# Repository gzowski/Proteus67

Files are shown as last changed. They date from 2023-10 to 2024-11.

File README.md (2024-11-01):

# Proteus67 - Ortholinear mechanical keyboard

* 67 Key ortholinear design, inspiration taken from the split design of the Sofle/Lily58 and Planck
* 33 keys per hand
* 1 Rotary encoder in the middle (Green)
* Additional column positioned each side down the centre. (Orange)
* Single microcontroller design while retaining characteristics of a split layout
* 130mm finger spacing while hands are at home positions (F/J keys) in a QWERTY layout. (Blue)

* As there is no base plate by default, I've provided PCB files and laser cutting stencils which can be fabricated, if mounting on a plate you'll also require M2 standoff's and screws.
* There is also a 3D printed case STL which fits the keyboard with the PCB resting on printed supports within the case, mounting screws not required.
* Firmware now part of QMK official repo: https://github.com/qmk/qmk_firmware
   * If you need any assistance with building your firmware then please reach out.
* Fully supported with VIA when flashed with VIA keymap: https://usevia.app/

### [Parts](#Parts) || [Assembly Guide](#Assembly-Guide)

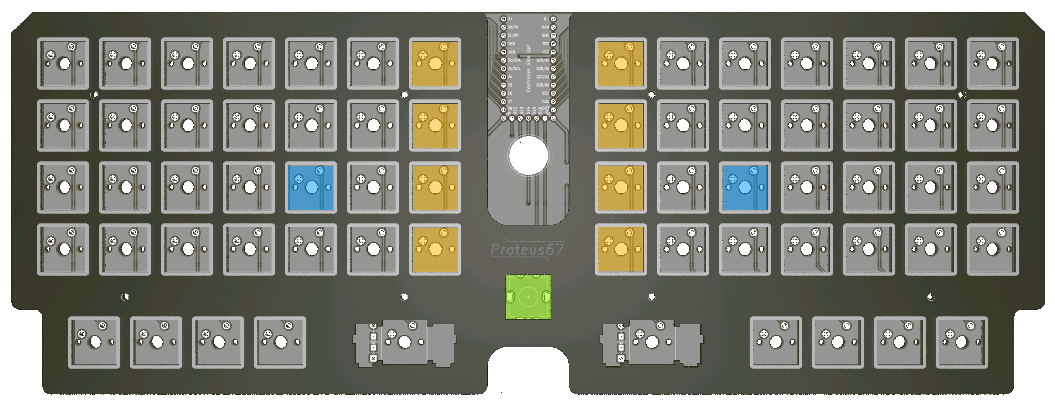
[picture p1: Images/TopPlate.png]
PCB

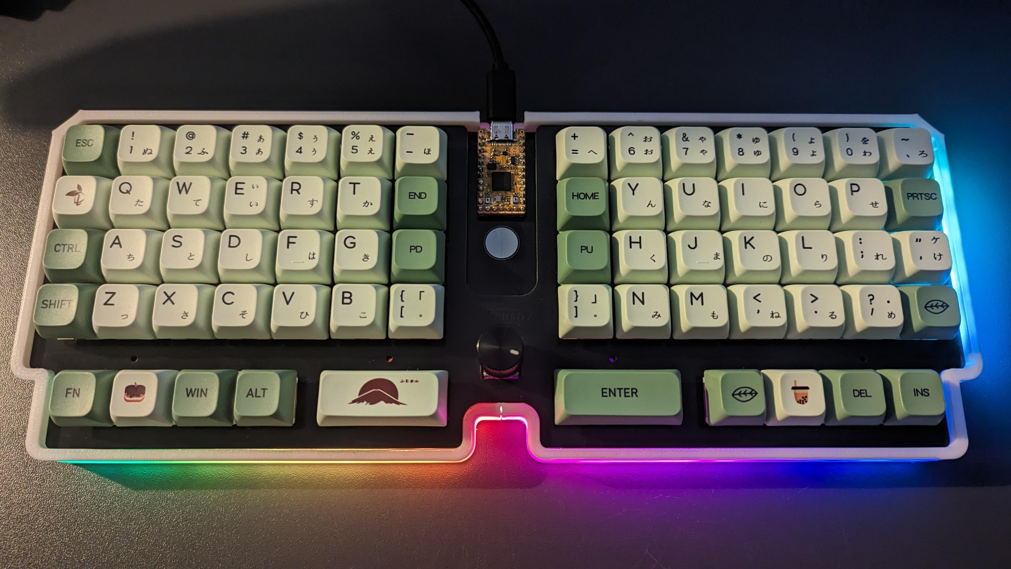
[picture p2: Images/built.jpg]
Personal build

## Parts

| Part | Quantity | Description | 
| :--- | :--- | :--- |
| Diodes| 67  | Through-hole 1N4148 or SMD 1N4148W |
| Microcontroller | 1 | 24 IO Pins required Elite-Pi/Frood or similar RP2040 |
| MX Switches | 66 | Cherry MX compatible switches |
| EC11 | 1 | Rotary Encoder for centre |
| MJTP1117 | 1 | Angled reset switch, (legs need cutting off) |
| Keycaps | 66 | 64x1u switches and 2x2u switches |
| Stabalizers | 2 | 2u plate mounted |

All components can be purchased through [mechboards.co.uk](https://mechboards.co.uk)

(Optional):
| Part | Quantity | Description |
| :--- | :--- | :--- |
| LED Strip | 1 | WS2812 Compatible (30cm) |
| 3D printed case | 1 | [3D printed case, STL/gcode](https://github.com/gzowski/Proteus67/tree/main/case) |
| PCB Base Plate | 1 | Bottom of case, covers underside |
| Base Plate Cutout | 1 | [STEP file of base plate outline which can be laser cut](https://github.com/gzowski/Proteus67/tree/main/case) |

## Assembly Guide

* I have provided additional images [here](https://github.com/gzowski/Proteus67/blob/main/Images/help_images.jpg) which show assembly.
* Place both stabalizers into the top plate
* Insert all switches into the top plate and put to the side
* Diode installation: Must be on the rear of the board due to lack of clearance from stabalisers.
  * SMD mounting: Use smaller diode points marked below, ensure diodes are facing the correct orientation
  * Through-Hole mounting: Use the wider spacing through-holes, ensuring diodes are facing the correct orientation.
    * Snip off excess on top side.
* Reset switch: snip off legs before positioning on board.
  *  Place switch on top side of PCB and solder from underside
* Microcontroller needs to be positioned with the top of the board facing upwards (Test controller beforehand and flash firmware using QMK)
* Place the rotary encoder on the top side and solder all points ensuring it stays flush to the board.
* Press down the top plate with switches and stabalisers down on the middle plate ensuring that all the switches sit flush against the middle plate.
* Turn board over and proceed to solder switches to the board
* Connect USB to keyboard and check all keys are functional, this is assuming you've already flashed the firmware to the MCU.

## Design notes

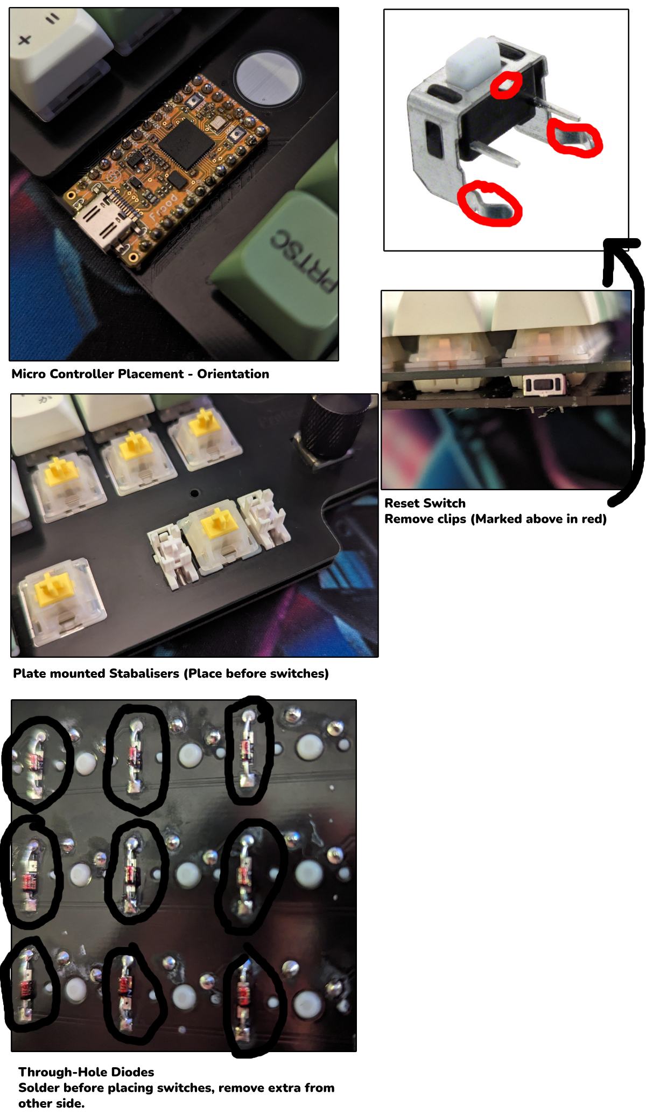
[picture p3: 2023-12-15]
Images/help_images.jpg

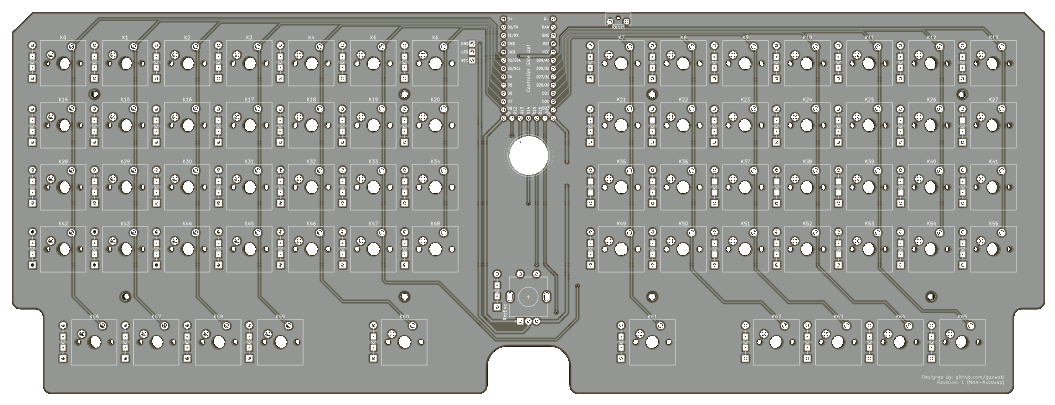
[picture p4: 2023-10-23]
Images/PCB.png

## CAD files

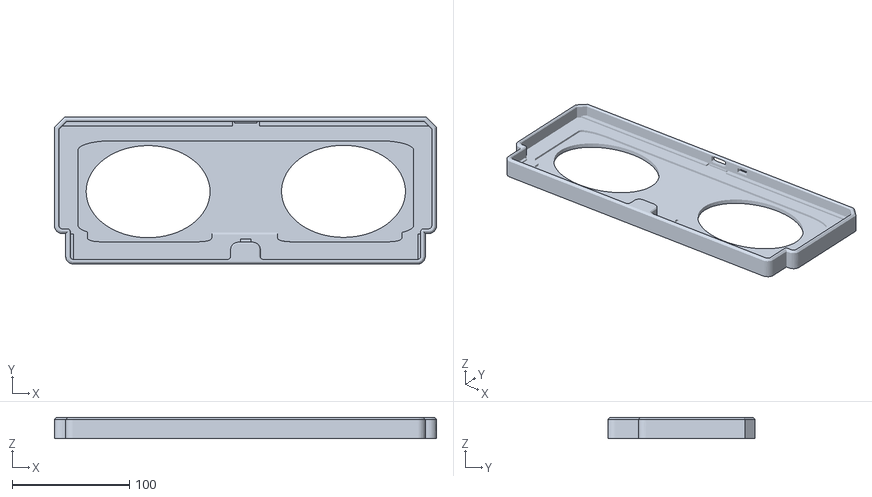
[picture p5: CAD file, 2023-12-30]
case/case_hollow_base_nocurve_front.stl
325.4 x 125.3 x 18.0

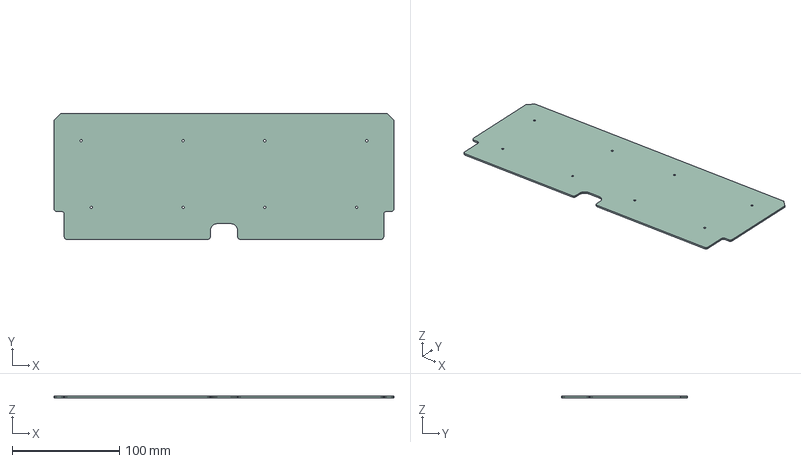
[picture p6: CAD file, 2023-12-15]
case/stencil for laser cutters/Plate.step
317.4 x 117.3 x 1.60 mm

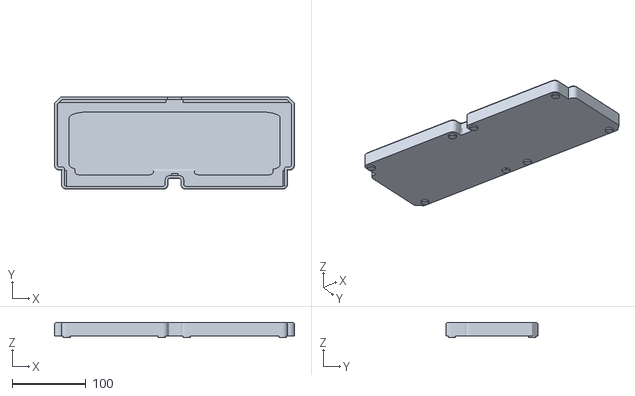
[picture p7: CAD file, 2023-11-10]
case/Case_original.stl
325.4 x 125.3 x 20.2

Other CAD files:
case/stencil for laser cutters/Plate.dxf

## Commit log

2023-10-15 Sun Oct 15 09:37:59 PM BST 2023
    [Proteus_Base.kicad_pcb, Proteus_PCB.kicad_pcb, Proteus_Top.kicad_pcb]
2023-10-16 Mon Oct 16 12:56:28 PM BST 2023
    [Lily58_Pro_TOP.kicad_pcb, Proteus_Top.kicad_pcb]
2023-10-16 Mon Oct 16 05:38:32 PM BST 2023
    [Proteus_Base.step, Proteus_Top.kicad_pcb, Proteus_Top.step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]
2023-10-17 Tue Oct 17 08:37:44 PM BST 2023
    [Proteus_PCB.kicad_pcb, base_Plate 1.stl]
2023-10-17 Tue Oct 17 08:39:14 PM BST 2023
    [top_Plate 1.stl]
2023-10-18 Wed Oct 18 11:14:47 AM BST 2023
    [Proteus_Top.step]
2023-10-23 Mon Oct 23 02:52:20 PM BST 2023
    [LeftPCB.stl, Proteus_Base.step, Proteus_PCB.kicad_pcb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]
2023-10-31 Tue Oct 31 12:33:12 PM GMT 2023
    [LeftPCB.stl, LeftPanel.stl, RightPCB.stl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]
2023-11-05 Sun Nov 5 11:47:03 PM GMT 2023
    [CaseFull.stl, LeftPanel.stl, RightPanel.stl]
2023-11-09 Thu Nov 9 10:01:54 PM GMT 2023
    [Proteus_Base-Edge_Cuts.dxf]
2023-11-10 Fri Nov 10 05:08:51 PM GMT 2023
    [mini_board.kicad_pcb]
2023-11-11 Sat Nov 11 10:19:21 AM GMT 2023
    [Case.stl, Proteus_Base-Edge_Cuts.dxf]
2023-12-15 Rename case/Proteus_Base.step to case/stencil for laser cutters/Plate.step
    [Plate.step]
